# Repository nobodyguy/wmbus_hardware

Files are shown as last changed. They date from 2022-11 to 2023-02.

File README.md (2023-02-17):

# WM-bus to USB board
* KiCAD 6.X required 
* iM871A module
* includes USB ESD protection
* includes CH340E UART IC

## Software
Tested with https://github.com/weetmuts/wmbusmeters library.

## Board overview
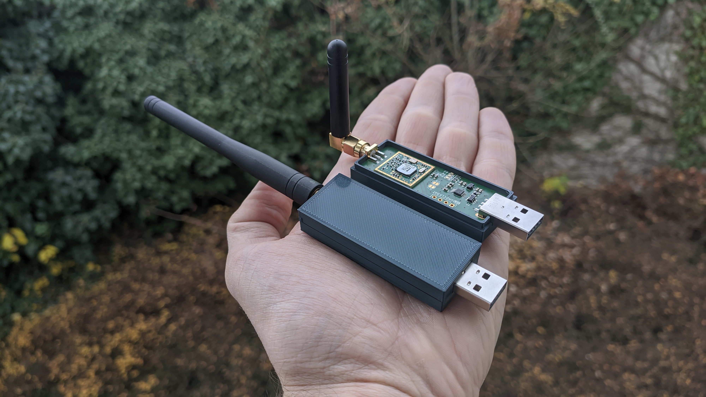
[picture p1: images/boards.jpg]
Boards

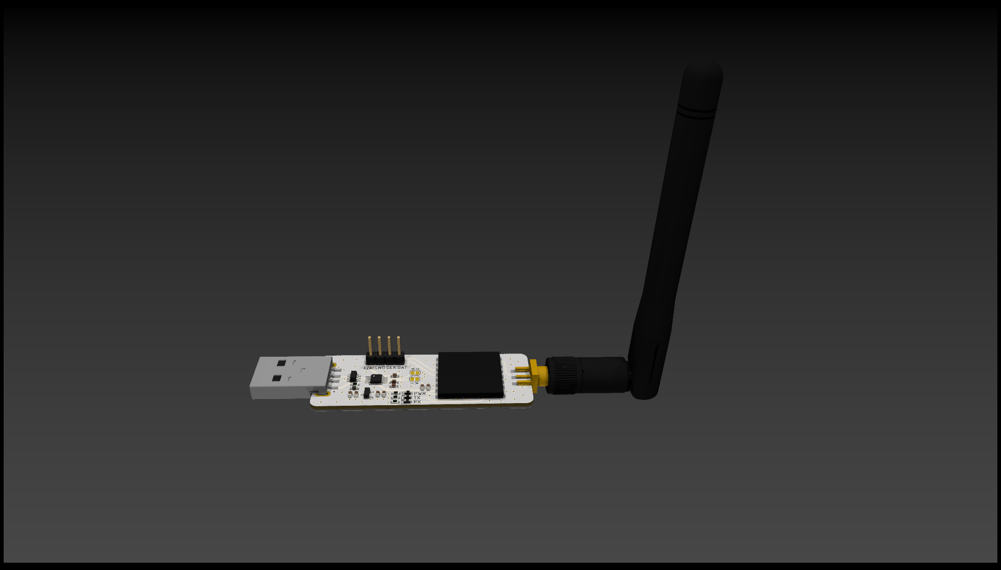
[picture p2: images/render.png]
Render 1

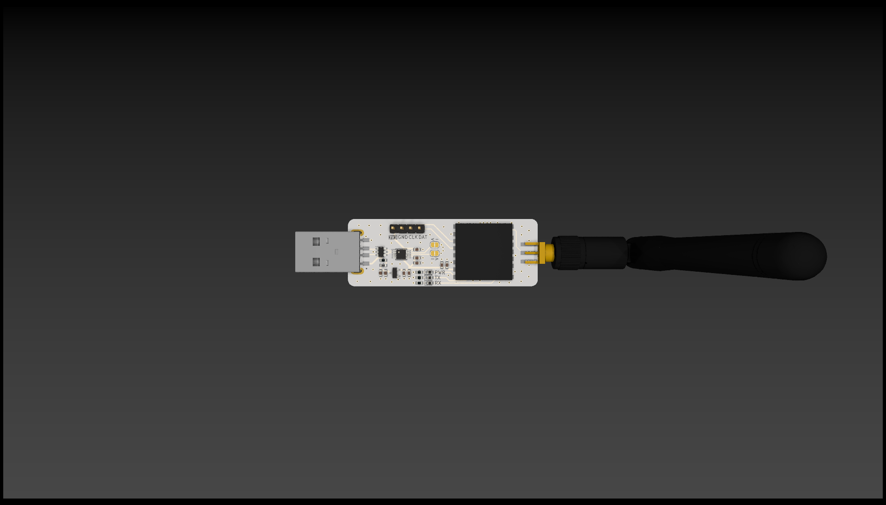
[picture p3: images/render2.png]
Render 2


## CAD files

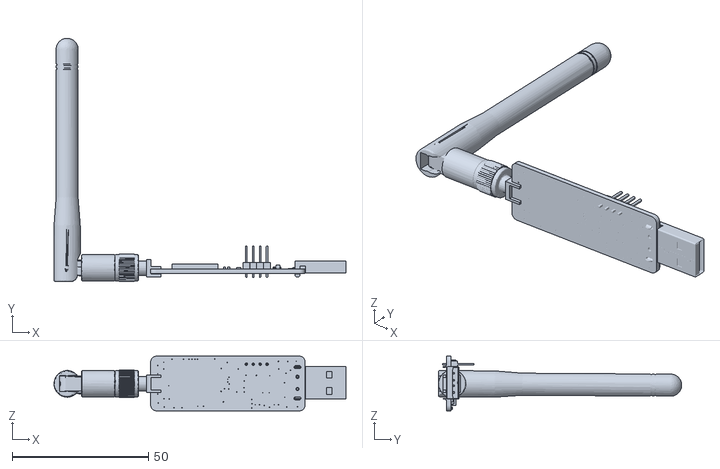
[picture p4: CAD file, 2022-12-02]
3D/box/wmbus_pcb.stl
107.1 x 89.3 x 20.0

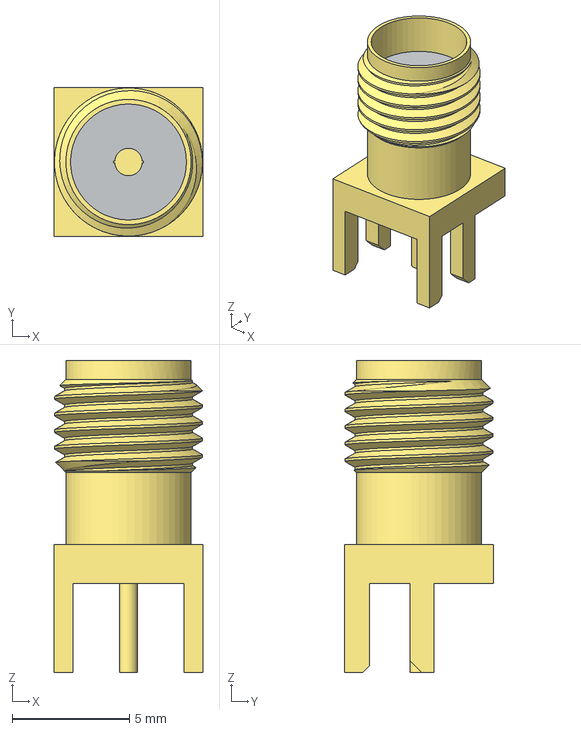
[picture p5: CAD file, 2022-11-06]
3D/WE_60312202111527.stp
6.35 x 6.35 x 13.3 mm

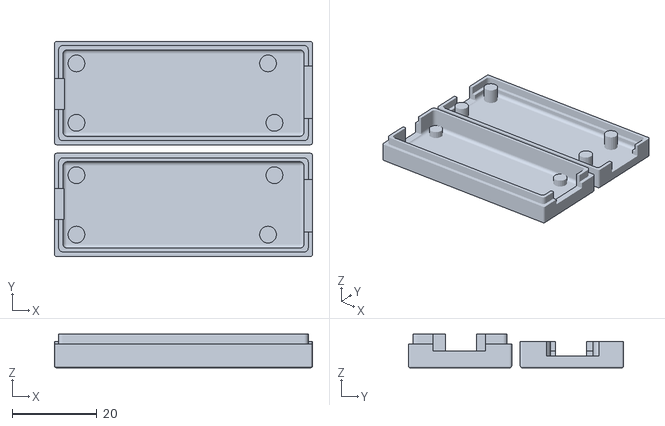
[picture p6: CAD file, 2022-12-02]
3D/box/wmbus_box.stl
61.0 x 50.9 x 8.00

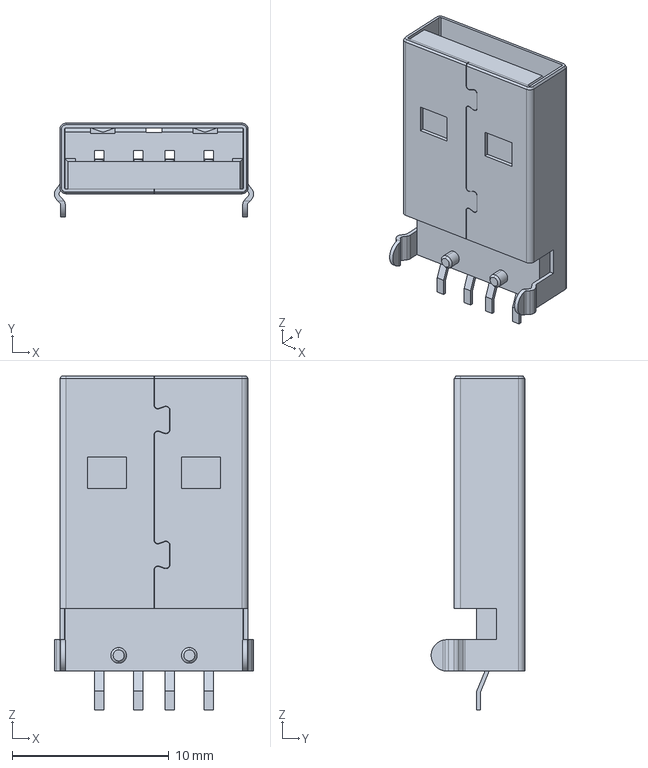
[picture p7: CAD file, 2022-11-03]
3D/480-37-1000.step
12.7 x 5.97 x 21.3 mm

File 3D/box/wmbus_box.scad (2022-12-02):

//---------------------------------------------------------
// Yet Another Parameterized Projectbox generator
//
//  This is a box for MBUS
//
//  Version 0.2
//
// This design is parameterized based on the size of a PCB.
//---------------------------------------------------------
include <./library/YAPPgenerator_v14.scad>

// Note: length/lengte refers to X axis, 
//       width/breedte to Y, 
//       height/hoogte to Z

/*
      padding-back|<------pcb length --->|<padding-front
                            RIGHT
        0    X-as ---> 
        +----------------------------------------+   ---
        |                                        |    ^
        |                                        |   padding-right 
        |                                        |    v
        |    -5,y +----------------------+       |   ---              
 B    Y |         | 0,y              x,y |       |     ^              F
 A    - |         |                      |       |     |              R
 C    a |         |                      |       |     | pcb width    O
 K    s |         |                      |       |     |              N
        |         | 0,0              x,0 |       |     v              T
      ^ |   -5,0  +----------------------+       |   ---
      | |                                        |    padding-left
      0 +----------------------------------------+   ---
        0    X-as --->
                          LEFT
*/

printBaseShell      = true;
printLidShell       = true;

// Edit these parameters for your own board dimensions
wallThickness       = 2.0;
basePlaneThickness  = 2.0;
lidPlaneThickness   = 2.0;

baseWallHeight      = 6;
lidWallHeight       = 2;

// ridge where base and lid off box can overlap
// Make sure this isn't less than lidWallHeight
ridgeHeight         = 2.8;
ridgeSlack          = 0.2;
roundRadius         = 0.5;

// How much the PCB needs to be raised from the base
// to leave room for solderings and whatnot
standoffHeight      = 2.0;
pinDiameter         = 2.0;
pinHoleSlack        = 0.1;
standoffDiameter    = 4.0;

// Total height of box = basePlaneThickness + lidPlaneThickness 
//                     + baseWallHeight + lidWallHeight
pcbLength           = 56.63;
pcbWidth            = 20.05;
pcbThickness        = 1.6;
                            
// padding between pcb and inside wall
paddingFront        = 0.2;
paddingBack         = 0.2;
paddingRight        = 0.2;
paddingLeft         = 0.2;


//-- D E B U G -------------------
showSideBySide      = true;
hideLidWalls        = false;
onLidGap            = 0;
shiftLid            = 0;
colorLid            = "yellow";
hideBaseWalls       = false;
colorBase           = "white";
showPCB             = false;
showMarkers         = false;
inspectX            = 0;  // 0=none, >0 from front, <0 from back
inspectY            = 0;  // 0=none, >0 from left, <0 from right

labelsPlane = [];
//-- pcb_standoffs  -- origin is pcb[0,0,0]
// (0) = posx
// (1) = posy
// (2) = { yappBoth | yappLidOnly | yappBaseOnly }
// (3) = { yappHole, YappPin }
pcbStands = [
                [3,  3, yappBoth, yappPin],
                [pcbLength-6.80,  pcbWidth-3, yappBoth, yappPin],
                [pcbLength-8.32,  3, yappBoth, yappPin],
                [3, pcbWidth-3, yappBoth, yappPin],
             ];
  

//-- Lid plane    -- origin is pcb[0,0,0]
// (0) = posx
// (1) = posy
// (2) = width
// (3) = length
// (4) = angle
// (5) = { yappRectangle | yappCircle }
// (6) = { yappCenter }
/*
cutoutsLid =  [
                  [pcbLength+1, pcbWidth/2, 12, 3, 0, yappRectangle, yappCenter]
              ];
    
  */            

//-- base plane    -- origin is pcb[0,0,0]
// (0) = posx
// (1) = posy
// (2) = width
// (3) = length
// (4) = angle
// (5) = { yappRectangle | yappCircle }
// (6) = { yappCenter }
//cutoutsBase =   [
//[2.60,  2.53, 2, 0, 0,yappCircle, yappCenter]
//                    [10, 10, 20, 10, 45, yappRectangle]
//                  , [30, 10, 15, 10, 45, yappRectangle, yappCenter]
//                  , [20, pcbWidth-20, 15, 0, 0, yappCircle]
//                  , [pcbLength-15, 5, 10, 2, 0, yappCircle]
//                ];

//-- front plane  -- origin is pcb[0,0,0]
// (0) = posy
// (1) = posz
// (2) = width
// (3) = height
// (4) = angle
// (5) = { yappRectangle | yappCircle }
// (6) = { yappCenter }
cutoutsFront =  [
[pcbWidth/2-0.2, 3.6, 12.4, 5.2, 0, yappRectangle, yappCenter]
//                 [25, 3, 10, 10, 0, yappRectangle, yappCenter]  // center
                ];

//-- back plane  -- origin is pcb[0,0,0]
// (0) = posy
// (1) = posz
// (2) = width
// (3) = height
// (4) = angle
// (5) = { yappRectangle | yappCircle }
// (6) = { yappCenter }
cutoutsBack =   [
                    [pcbWidth/2-3.5, -3.2, 7.4, 7.4, 0, yappRectangle]                // org
                  
                ];

//-- left plane   -- origin is pcb[0,0,0]
// (0) = posx
// (1) = posz
// (2) = width
// (3) = height
// (4) = angle
// (5) = { yappRectangle | yappCircle }
// (6) = { yappCenter }
//cutoutsLeft =   [
//                    [25, 0, 6, 20, 0, yappRectangle]                        // org
//                  , [pcbLength-35, 0, 20, 6, 0, yappRectangle, yappCenter] // center
//                  , [pcbLength/2, 10, 20, 6, 0, yappCircle]                // circle
//                ];

//-- right plane   -- origin is pcb[0,0,0]
// (0) = posx
// (1) = posz
// (2) = width
// (3) = height
// (4) = angle
// (5) = { yappRectangle | yappCircle }
// (6) = { yappCenter }
//cutoutsRight =  [
//                    [10, 0, 9, 5, 0, yappRectangle]                // org
//                  , [40, 0, 9, 5, 0, yappRectangle, yappCenter]    // center
//                  , [60, 0, 9, 5, 0, yappCircle]                   // circle
//                ];

//-- connectors -- origen = box[0,0,0]
// (0) = posx
// (1) = posy
// (2) = screwDiameter
// (3) = insertDiameter
// (4) = outsideDiameter
// (5) = { yappAllCorners }
//connectors   =  [
//                    [8, 8, 2.5, 3.8, 5, yappAllCorners]
//                  , [30, 8, 5, 5, 5]
//                ];

//-- base mounts -- origen = box[x0,y0]
// (0) = posx | posy
// (1) = screwDiameter
// (2) = width
// (3) = height
// (4..7) = yappLeft / yappRight / yappFront / yappBack (one or more)
// (5) = { yappCenter }
//baseMounts   = [
//                    [-5, 3.5, 10, 3, yappRight, yappCenter]
//                  , [0, 3.5, shellLength, 3, yappLeft, yappCenter]
//                  , [0, 3.5, 33, 3, yappLeft]
//                  , [shellLength, 3.5, 33, 3, yappLeft]
//                  , [shellLength/2, 3.5, 30, 3, yappLeft, yappCenter]
//                  , [10, 3.5, 15, 3, yappBack, yappFront]
//                  , [shellWidth-10, 3.5, 15, 3, yappBack, yappFront]
//               ];
               
//-- snap Joins -- origen = box[x0,y0]
// (0) = posx | posy
// (1) = width
// (2..5) = yappLeft / yappRight / yappFront / yappBack (one or more)
// (n) = { yappSymmetric }

/*snapJoins   =     [
                    [2, 10, yappLeft, yappRight, yappSymmetric]
              //    [5, 10, yappLeft]
              //  , [shellLength-2, 10, yappLeft]
               //   , [30,  10, yappFront, yappBack]
              //  , [2.5, 3, 5, yappBack, yappFront, yappSymmetric]
                ];
*/               
//-- origin of labels is box [0,0,0]
// (0) = posx
// (1) = posy/z
// (2) = orientation
// (3) = plane {lid | base | left | right | front | back }
// (4) = font
// (5) = size
// (6) = "label text"
//labelsPlane =  [
//                    [10,  10,   0, "lid",   "Liberation Mono:style=bold", 7, "YAPP" ]
//                  , [100, 90, 180, "base",  "Liberation Mono:style=bold", 7, "Base" ]
//                  , [8,    8,   0, "left",  "Liberation Mono:style=bold", 7, "Left" ]
//                  , [10,   5,   0, "right", "Liberation Mono:style=bold", 7, "Right" ]
//                  , [40,  23,   0, "front", "Liberation Mono:style=bold", 7, "Front" ]
//                  , [5,    5,   0, "back",  "Liberation Mono:style=bold", 7, "Back" ]
//               ];
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

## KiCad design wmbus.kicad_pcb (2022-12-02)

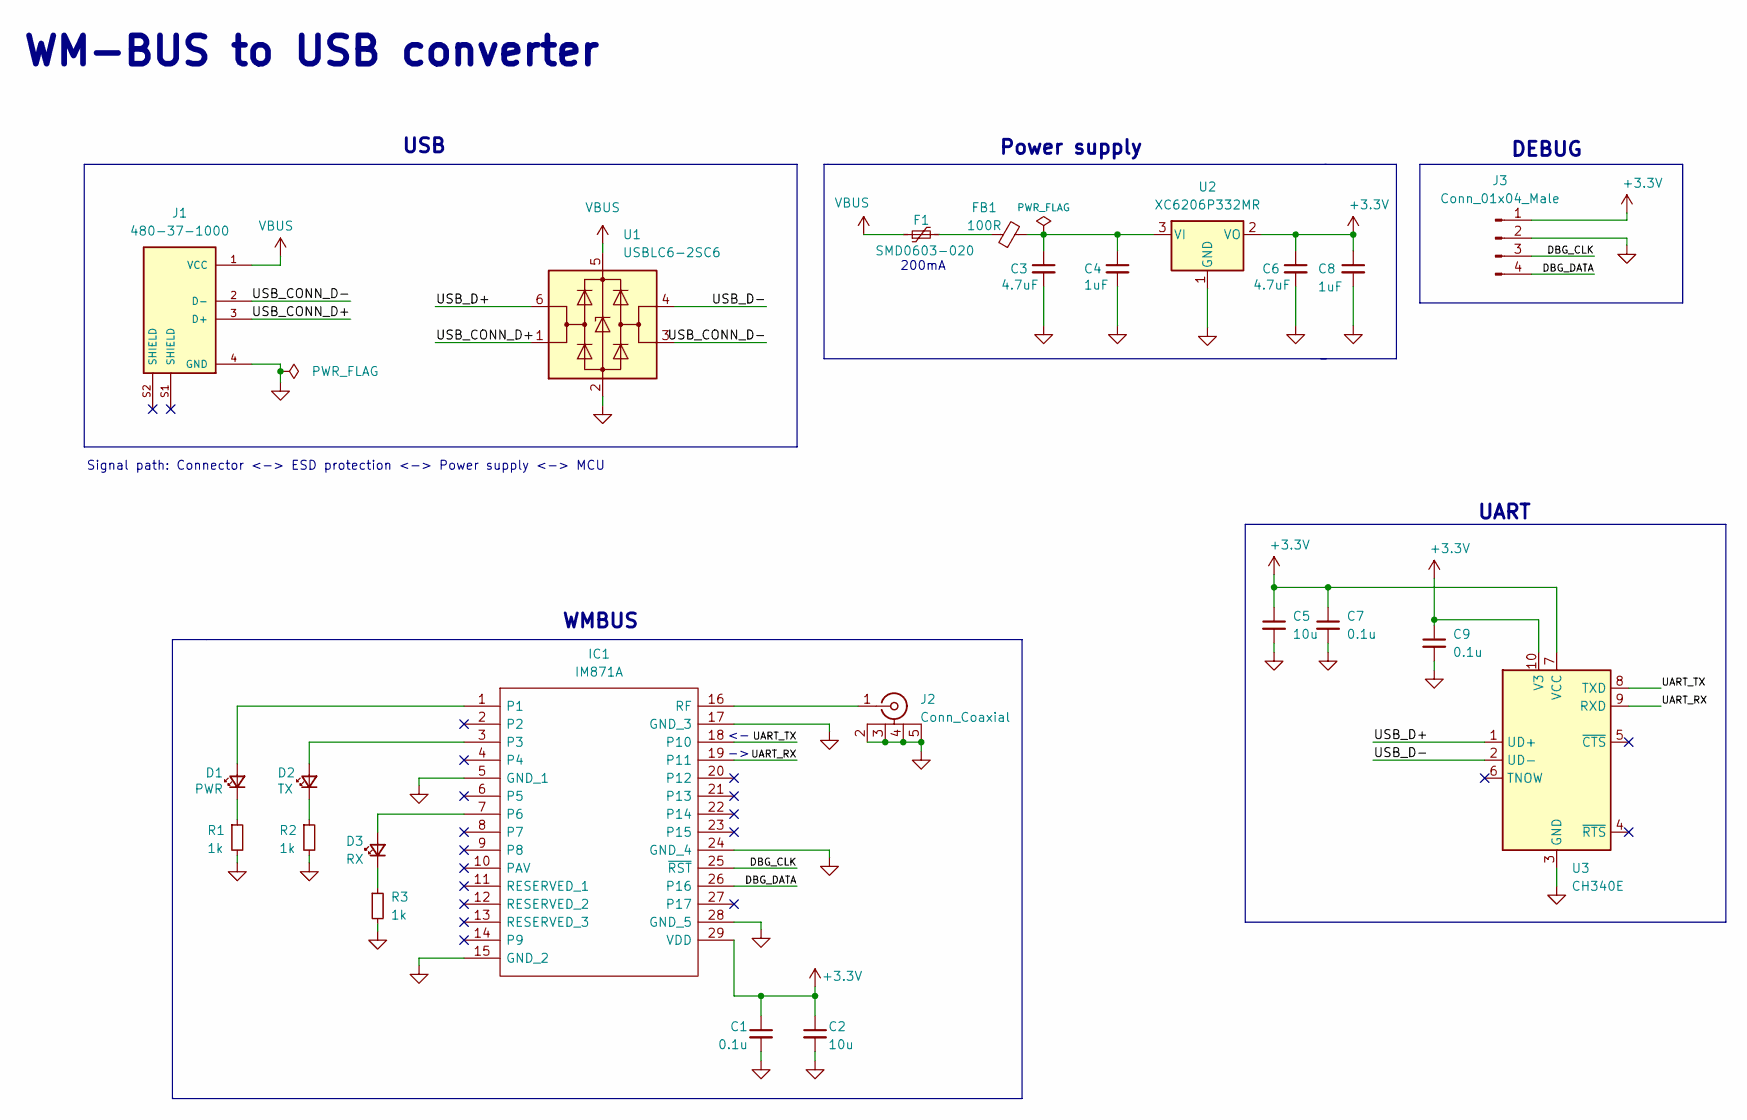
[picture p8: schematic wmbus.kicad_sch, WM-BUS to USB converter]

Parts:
C1, C7, C9: 0.1u; C_0603_1608Metric; LCSC Part C14663
C2, C5: 10u; C_0603_1608Metric; LCSC Part C109455
C3, C6: 4.7uF; C_0603_1608Metric; LCSC Part C1592
C4, C8: 1uF; C_0603_1608Metric; LCSC Part C1592
D1: PWR; D_0603_1608Metric; LCSC Part C72043
D2: TX; D_0603_1608Metric; LCSC Part C72043
D3: RX; D_0603_1608Metric; LCSC Part C72043
F1: SMD0603-020; Fuse_0603_1608Metric; LCSC Part C2760255
FB1: 100R; L_0603_1608Metric; LCSC Part C74325
IC1: IM871A; Manufacturer_Part_Number IM871A
J1: 480-37-1000; MOLEX_480-37-1000; PARTREV D
J2: Conn_Coaxial; SMA-SMD_BWSMA-KE-P001
J3: Conn_01x04_Male; PinHeader_1x04_P2.54mm_Vertical
R1, R2, R3: 1k; R_0603_1608Metric; LCSC Part C22548
U1: USBLC6-2SC6; SOT-23-6; LCSC Part C2827654
U2: XC6206P332MR; SOT-23; LCSC Part C5446
U3: CH340E; MSOP-10_3x3mm_P0.5mm; LCSC Part C99652

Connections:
+3.3V: C1.1, C2.1, C5.1, C6.1, C7.1, C8.1, C9.1, IC1.29 (VDD), J3.1, U2.2 (VO), U3.7 (VCC), U3.10 (V3)
/DBG_CLK: IC1.25 (~RST), J3.3
/DBG_DATA: IC1.26 (P16), J3.4
/UART_RX: IC1.19 (P11), U3.9 (RXD)
/UART_TX: IC1.18 (P10), U3.8 (TXD)
/USB_CONN_D+: J1.3 (D+), U1.1 (I/O1)
/USB_CONN_D-: J1.2 (D-), U1.3 (I/O2)
/USB_D+: U1.6 (I/O1), U3.1 (UD+)
/USB_D-: U1.4 (I/O2), U3.2 (UD-)
GND: C1.2, C2.2, C3.2, C4.2, C5.2, C6.2, C7.2, C8.2, C9.2, IC1.5 (GND_1), IC1.15 (GND_2), IC1.17 (GND_3), IC1.24 (GND_4), IC1.28 (GND_5), J1.4 (GND), J2.2 (Ext), J2.3 (Ext), J2.4 (Ext), J2.5 (Ext), J3.2, R1.2, R2.2, R3.2, U1.2 (GND), U2.1 (GND), U3.3 (GND)
unnamed: C3.1, C4.1, FB1.2, U2.3 (VI)
unnamed: D1.1 (K), R1.1
unnamed: D1.2 (A), IC1.1
unnamed: D2.1 (K), R2.1
unnamed: D2.2 (A), IC1.3
unnamed: D3.1 (K), R3.1
unnamed: D3.2 (A), IC1.7 (P6)
unnamed: F1.2, FB1.1
unnamed: IC1.16 (RF), J2.1 (In)
VBUS: F1.1, J1.1 (VCC), U1.5 (VBUS)

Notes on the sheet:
200mA
UART
WMBUS
DEBUG
Signal path: Connector <-> ESD protection <-> Power supply <-> MCU
USB
Power supply
WM-BUS to USB converter

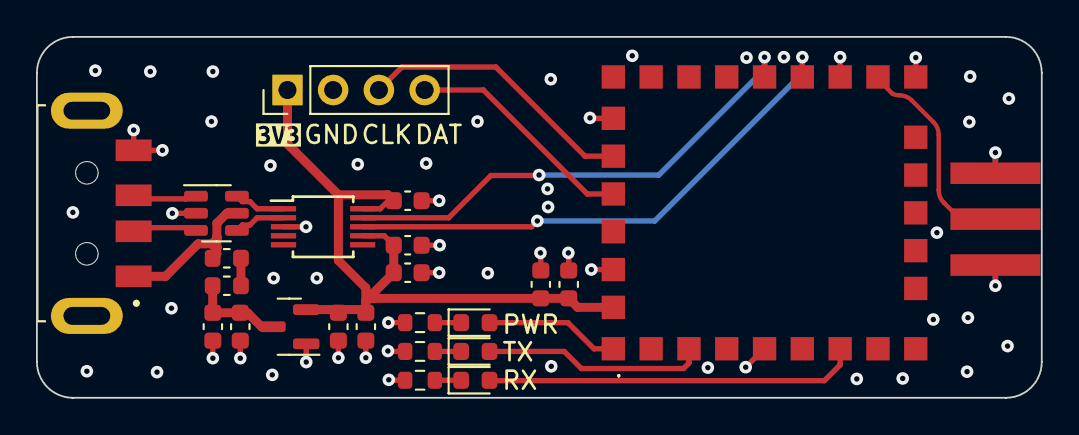
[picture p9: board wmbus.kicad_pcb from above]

Board: 4 copper layers, 55.8 x 20.0 mm, 26 parts (1 on the bottom side), 20 nets.

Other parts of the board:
kibuzzard-636EC376: G***; kibuzzard-636EC376
kibuzzard-6361777F: G***; kibuzzard-6361777F

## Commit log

2022-11-03 Initial version without routing
    [480-37-1000.step, IM871A.stp, SMA.STEP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]
2022-11-03 Routing done
    [wmbus.kicad_pcb, wmbus.kicad_sch]
2022-11-04 Ready for production rev1
    [wmbus.kicad_pcb, wmbus.kicad_sch]
2022-11-06 Added antenna 3D model, removed useless GND via, unified via size
    [wmbus.kicad_pcb]
2022-11-06 Updated SMA connector 3D model
    [SMA.STEP, WE_60312202111527.stp]
2022-12-02 Rounded RF track
    [wmbus.kicad_pcb]
2022-12-02 Added 3D printed box
    [wmbus_box.scad, wmbus_box.stl, wmbus_pcb.stl]
2022-12-02 rev2 - smaller, removed unused rx/tx jumpers
    [wmbus.kicad_pcb, wmbus.kicad_sch]
2023-02-17 Added photo of real boards
